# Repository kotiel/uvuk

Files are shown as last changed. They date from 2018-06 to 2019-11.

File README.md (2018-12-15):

# UvuKCube

<br />This work is licensed under a <a rel="license" href="http://creativecommons.org/licenses/by-nc-sa/4.0/">Creative Commons Attribution-NonCommercial-ShareAlike 4.0 International License</a>.

<p align="center" >
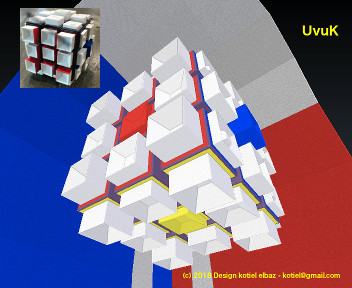
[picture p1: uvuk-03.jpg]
UvuKCube
  
</p>

> Princess UvuKiri, UvuKCube's sister to help you playing with the UvuKCube - fun to build for the children.

> Follow **@uvukcube** on Instagram and Twitter, soon the UvuKiri build guide.

## Qu’est-ce l’UvuK Cube?

La capacité de l’esprit à anticiper un parcours 3D d'une position A vers une position B dans l’espace 3D s'apprend.
**UvuKCube** vous permet d’imaginer ce parcours en 3D (Troisième Dimension), avec vos sensations tactiles du bout des doigts guidées par les cubignons **PiK** et **LaK**.

## What is the UvuKCube?

Imagine you could improve your mind path 3D modeler to move objects around in 3D Space.

**UvuKCube** allows you to imagine a 3D path and execute it, even if you were visually impaired - with your fingers tips, thanks to the cubignons **PiK** and **LaK**.

Discover 3D Printing, Blender3D, even the documentation explains how to re-do a cube.

Trop cool Instagram video of [cubignons](https://instagram.com/p/BknzR3xnqnM/) being 3D printed. 

> Hello cubers.

> UvuKCube is a 3D Kit to bring the Rubik’s cube in the classroom of visually impaired children - Your help is welcome as you build it yourself by 3D printing the ‘CUBIGNONS PiK and LaK’ and then give it to a blind child. Thanks to the UvuKCube, the colours become a sensitive feeling.
A lot to learn 3D software BLENDER3D, 3D Printers, Cubignons PiK and LaK, concave, convex, painting, glue and a lot of fun to teach a blind child to master UvuKCube as well as you master the Rubik’s cube.
UvuKCube’s Cubignons PiK and LaK are Creative Commons, you are free to 3D print them, to modify them to create new UvuKCube.

Thanks to [La Cité des Sciences Fab Lab Paris](http://carrefour-numerique.cite-sciences.fr/fablab/wiki/doku.php?id=projets:uvuk_cube)

``` bash
To follow the Cubignons PiK and LaK, and more
FB fb.me/uvukcube
Instagram @uvukcube #uvukcube
Email uvukcube@gmail.com

Bon Courage, 2018, June 1st
> K.
```

<br />This work is licensed under a <a rel="license" href="http://creativecommons.org/licenses/by-nc-sa/4.0/">Creative Commons Attribution-NonCommercial-ShareAlike 4.0 International License</a>.

Licence Creative Commons Français (BY) (SA) (NC) https://creativecommons.org/licenses/by-nc/4.0/deed.fr

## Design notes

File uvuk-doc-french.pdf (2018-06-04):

# UvuK Cube

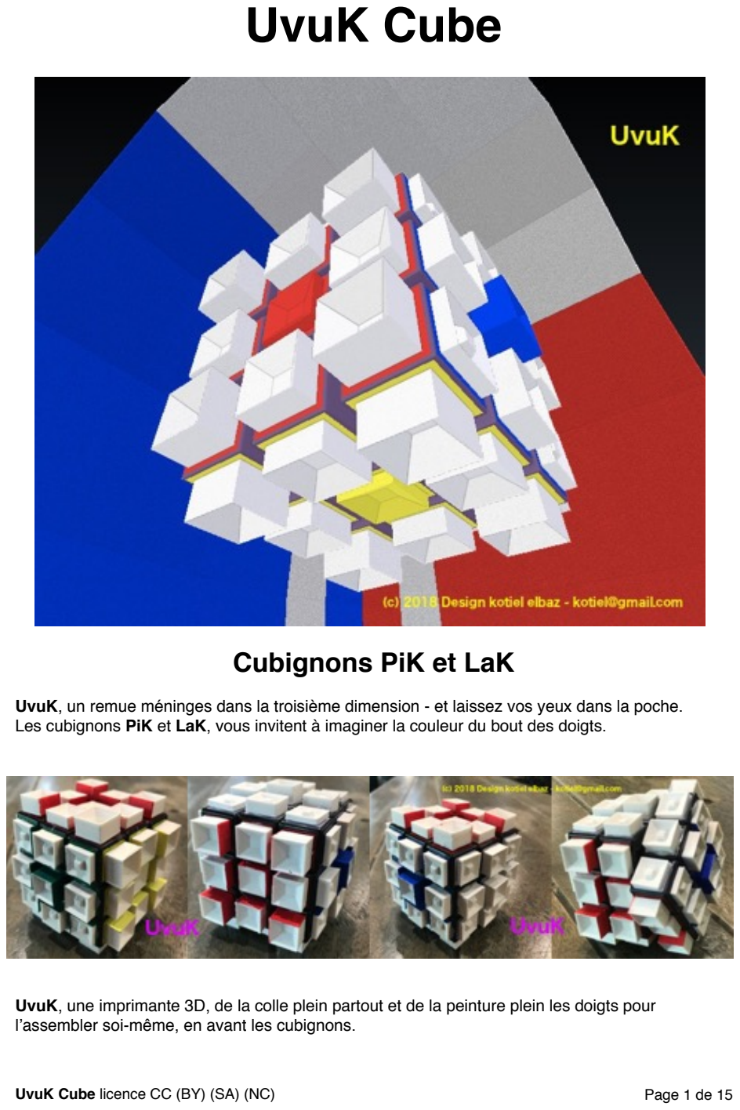
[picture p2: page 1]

## Cubignons PiK et LaK

UvuK, un remue méninges dans la troisième dimension - et laissez vos yeux dans la poche. Les cubignons PiK et LaK, vous invitent à imaginer la couleur du bout des doigts.

UvuK, une imprimante 3D, de la colle plein partout et de la peinture plein les doigts pour l’assembler soi-même, en avant les cubignons.

UvuK Cube licence CC (BY) (SA) (NC) | Page 1 de 15

UvuK Cube | 1
Cubignons PiK et LaK | 1
Assemblage | 3
La liste | 3
Uvuk Cube | 4
Uvuk Face | 5
Refaire Uvuk | 7
UvuK | 7
Les formules | 8
F01 - F02 - Rangée centrale | 9
F03 - Position Croix | 10
F04 - F05 - Orientation Croix | 11
F06 - Position Coins | 12
F07 - Orientation Coins | 13
Liste des fichiers | 14
Embûche | 15
Logiciel | 15
UvuK Licence | 15
UvuK Cube licence CC (BY) (SA) (NC) | Page 2 de 15

## Assemblage

## La liste

### Un Cube

La partie mécanique du Rubik’®s cube est utilisée comme un support.

- Un cube a six faces, chacune est composée de 9 facettes
- Les neuf facettes sont de la même couleur
- La facette centrale donne la couleur de la face
- La facette centrale reste à la même position malgré des rotations

### Le Cubignon

Le cubignon est un cube de la taille d’une facette. Il se colle sur une facette. Il y a deux types de cubignons
- Le cubignon LaK est une cuvette dépouillée
- Le cubignon PiK est une cuvette avec en son fond une bossette

PiK et LaK, les cubignons ont trois hauteurs : 9mm, 6mm et 3mm.

### Face de Cubignons

Une face est un ensemble de neuf cubignons PiK ou de neuf cubignons LaK.
L’ agencement des cubignons par hauteur permet de composer une face convexe ou concave. LA FACE CONVEXE
- Le cubignon central est le petit de 3mm, aux 4 coins se sont les grands de 9mm et les 4 sur les côtés, entre les coins se sont les moyens de 6mm
LA FACE CONCAVE
- Le cubignon central est le grand de 9mm, aux 4 coins sont les petits de 3mm et les 4 sur les côtés, entre les coins se sont les moyens de 6mm

### Collage du Cubignon

Avec un grand total de 54 cubignons crées avec une imprimante 3D, un fer à colle est moyen pratique pour les fixer sur les facettes d’un cube.

### Coloriage du Cubignon

On peut en exemple choisir comme couleur celle de la facette centrale de la face où on colle le cubignon :
- le cubignon central : peindre les quatre côtés
- le cubignon coin : peindre les deux côtés intérieures
- le cubignon côté : peindre le côté en vis à vis du cubignon central
UvuK Cube licence CC (BY) (SA) (NC) | Page 3 de 15

## Uvuk Cube

### Vues par Face

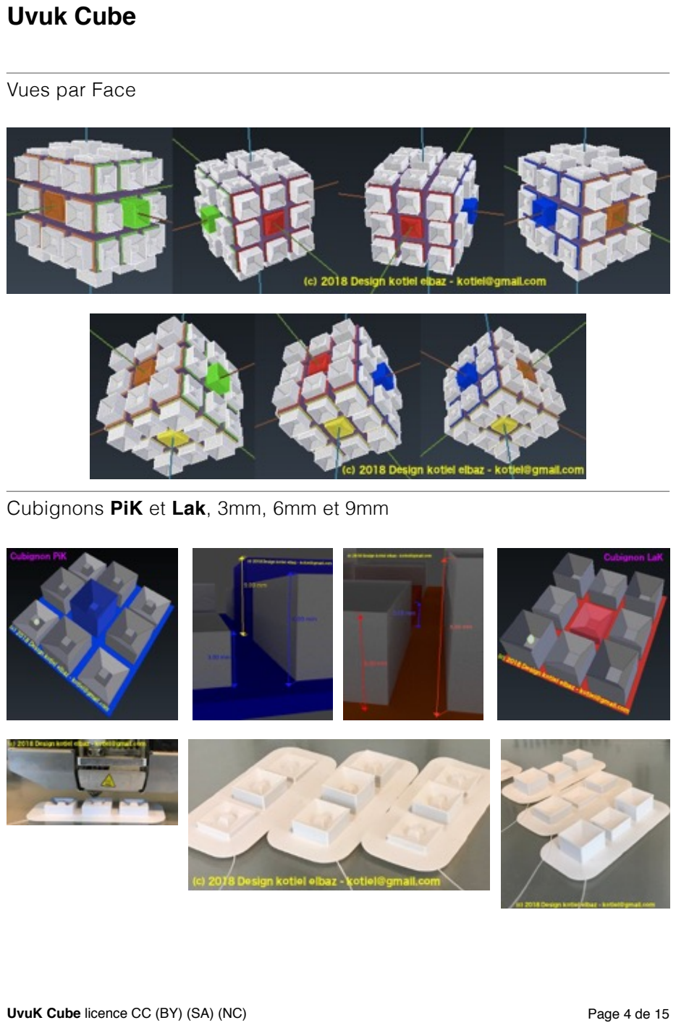
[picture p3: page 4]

### Cubignons PiK et Lak, 3mm, 6mm et 9mm

UvuK Cube licence CC (BY) (SA) (NC) | Page 4 de 15

## Uvuk Face

### Face Concave

Une face concave est composée de 9 cubignons.
Au centre, un cubignon de hauteur 9mm.
A droite, à gauche, au-dessus et en-dessous (en croix) du cubignon central, les cubignons ont une hauteur de 6mm - 4 cubignons.
Aux coins, les cubignons ont une hauteur de 3mm - 4 cubignons coins.

### Face Convexe

Une face convexe est composée de 9 cubignons.
Au centre, un cubignon de hauteur 3mm.
A droite, à gauche, au-dessus et en-dessous (en croix) du cubignon central, les cubignons ont une hauteur de 6mm - 4 cubignons.
Aux coins, les cubignons ont une hauteur de 9mm - 4 cubignons coins.

### La Face convexe et la Face concave

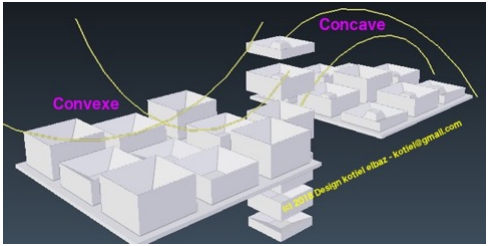
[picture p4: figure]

UvuK Cube licence CC (BY) (SA) (NC) | Page 5 de 15

### Assemblage UvuK

Impression 3D de
- 3 faces concaves de cubignons PiK
- 3 faces convexes de cubignons LaK

Collage des cubignons
- Face rouge, jaune et orange sont des faces convexes de cubignons LaK
- Face bleu, blanche et verte sont des faces concaves de cubignons PiK

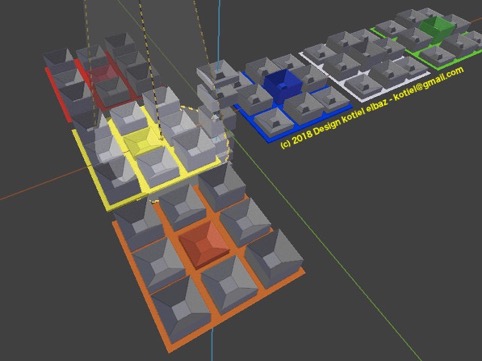
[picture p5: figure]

UvuK Cube licence CC (BY) (SA) (NC) | Page 6 de 15

## Refaire Uvuk

UvuK design permet de manipuler la position des cubignons d’un UvuK de manière tactile. Uvuk est composé de trois faces concaves PiK et de trois faces convexes LaK :
- La face avant (rouge) et la face arrière (orange) sont des faces convexes LaK
- La face gauche (verte) et la droite (bleu) sont des faces concaves PiK
- La face haute (blanche) est concave PiK et la face du dessous (jaune) est convexe LaK

## UvuK

Uvuk possède 6 faces, chacune avec huit facettes mobiles et une non-mobile.
En effet, le cubignon central est mécaniquement en bout d’axe - seule la rotation est possible. Les formules ci-dessous donnent une liste de sens de rotation gauche/droite ou avant/arrière par face afin de décrire les étapes pour déplacer des cubignons.
- Les faces avant, arrière, haute et bas pivotent vers la droite ou vers la gauche
- Les faces gauche et droite pivotent dans le sens en avant ou en arrière
La position de départ est un cubignon central LaK en dessous, un cubignon central LaK en avant et un cubignon central PiK en haut - la face rouge est devant.

### Central, Coin, Côté

Le coin : il est composé de trois facettes, sur une face adjacente différente - UvuK a six coins. Le côté : il est composé de deux facettes, sur une face adjacente différente - une face est composée de quatre cotés. Entre deux coins, il y a un côté - formant une croix autour du cubignon central.
UvuK, on trouve centre de chaque face un cubignon PiK de 3mm/9mm, ou bien un cubignon LaK de 3mm/9mm.
La hauteur 3mm ou 9mm du cubignon central détermine le type convexe ou concave d’une face.

### Identification des faces

Exemple : tourner la face à votre droite d’une rotation vers l’arrière s’écrit : FaceDroite.vers.arrière

| PiK | LaK | Convexe | Concave | Position par défaut | Sens de rotation
Rouge | | LaK | Convexe | | AVANT | Droite/Gauche
Orange | | LaK | Convexe | | ARRIÈRE | Droite/Gauche
Bleu | PiK | | | Concave | DROITE | Avant/Arrière
Vert | PiK | | | Concave | GAUCHE | Avant/Arrière
Blanc | PiK | | | Concave | HAUTE | Droite/Gauche
Jaune | | LaK | Convexe | | BAS | Droite/Gauche
UvuK Cube licence CC (BY) (SA) (NC) | Page 7 de 15

## Les formules

### Etape I - Face Haute

UvuK, une fois tous les cubignons mélangés, les formules suivantes permettent de déplacer les cubignons par étapes afin de les remettre tous en postions.
On commence par faire la face du haut. Il faut apprendre par soi-même cette étape, c’est un bon exercice pour la mémoire visuelle et tactile, aussi la maîtrise du déplacement des cubignons.

UvuK position de référence :
- un cubignon central LaK devant (rouge), un cubignon central LaK en bas (jaune) et un cubignon central PiK en haut (blanc)

Pour rassembler la première face :
- Positionner les quatre coins - quatre cubignons PiK de la face concave haute (blanche)
- Positionner les côtés - une situation embêtante est avec un cubignon du dessus est sur la face du dessous (jaune) - courage vous trouverez la solution
- Positionner les cubignons de la face afin que la couronne soit d’une couleur identique pour chaque face latérale - utiliser la couleur du cubignon central d’une face adjacente

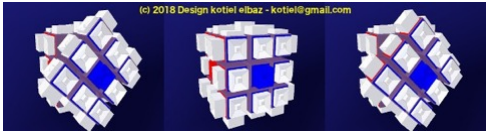
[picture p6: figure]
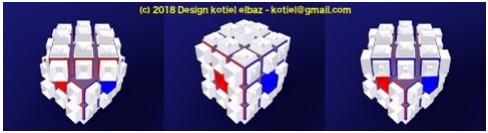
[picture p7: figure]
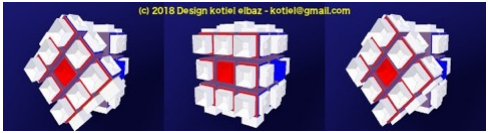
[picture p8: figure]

UvuK Cube licence CC (BY) (SA) (NC) | Page 8 de 15

### Etape II - Rangée centrale

La rangée centrale est composée de 4 cubignons centrals et de 4 cubignons côtés - on applique F01 ou F02 en complétant une face à la fois.
Seuls des cubignons côtés sont à positionner - 4 pour faire la rangée.

Quand un cubignon est en place et mal orienté, on applique en premier la formule F01 ou F02 avec un quelconque cubignon de la face du bas pour le déplacer, ensuite une nouvelle fois F01 ou F02 pour le positionner correctement.

F01 fait monter le cubignon de la face du bas vers la droite, la formule F02 vers la gauche.

## F01 - F02 - Rangée centrale

### F01 - Cubignon Bas va à Droite vers rangée centrale

### F02 - Cubignon Bas va à Gauche vers rangée centrale

Etape 1 | Etape 2 | Etape 3 | Etape 4
FaceBas.vers.gauche | FaceDroite.vers.avant | FaceBas.vers.droite | FaceDroite.vers.arrière
Etape 5 | Etape 6 | Etape 7 | Etape 8
FaceBas.vers.droite | FaceAvant.vers.droite | FaceBas.vers.gauche | FaceAvant.vers.gauche
Etape 1 | Etape 2 | Etape 3 | Etape 4
FaceBas.vers.droite | FaceGauche.vers.avant | FaceBas.vers.gauche | FaceGauche.vers.arrière
Etape 5 | Etape 6 | Etape 7 | Etape 8
FaceBas.vers.gauche | FaceAvant.vers.gauche | FaceBas.vers.droite | FaceAvant.vers.droite

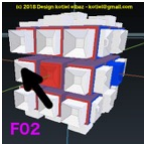
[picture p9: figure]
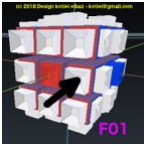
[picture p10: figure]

UvuK Cube licence CC (BY) (SA) (NC) | Page 9 de 15

### Etape III - Rangée du bas

On oriente Uvuk, avec la face convexe LaK (jaune) comme la face du dessus.

## F03 - Position Croix

L’objectif est une croix de quatre cubignons côtés autour du cubignon central (LaK de 3mm -jaune). On positionne la croix, sans se soucier de ses facettes adjacentes, c’est à dire les cubignons en croix sont tous des LaK de 6mm (jaune) au dessus, la position de l’anneau latéral se fait avec la prochaine formule.
F03 positionne seulement deux côtés à la fois. Quand on a deux cubignons adjacents, tournez la face pour orienter les deux cubignons en haut et à gauche.

La formule F03 est à utiliser plusieurs fois de suite, afin d’orienter les quatre cubignons.

### F03 - Position de croix

Etape 1 | Etape 2 | Etape 3 | Etape 4
FaceDroite.vers.avant | FaceHaute.vers.gauche | FaceAvant.vers.gauche | FaceHaute.vers.droite
Etape 5 | Etape 6
FaceAvant.vers.droite | FaceDroite.vers.arrière

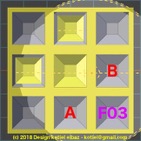
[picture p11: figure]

UvuK Cube licence CC (BY) (SA) (NC) | Page 10 de 15

## F04 - F05 - Orientation Croix

La croix du dessus - 4 cubignons LaK 6mm (jaune) - est en position. Les formules F04 et F05 permettent une rotation circulaire des cubignons côtés sans une modification d’orientation.
Les formules F04 et F05 déplacent le cubignon de la position A vers la droite (F04) ou bien vers le bas (F05). Dans certains cas, il est nécessaire d’appliquer F04 plusieurs fois de suite, pour obtenir la position de départ avec un bon côté à gauche - au besoin tourner la face du dessus pour sélectionner le cubignon à positionner à gauche avant d’appliquer F04.

Les formules F04 et F05 sont à connaître par coeur ;).

### F04 - Rotation circulaire, le cubignon haut va à droite

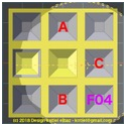
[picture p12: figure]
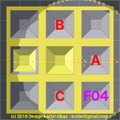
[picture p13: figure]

### F05 - Rotation circulaire, le cubignon haut va en bas

Etape 1 | Etape 2 | Etape 3 | Etape 4 | Etape 5
FaceDroite.vers.arrière | FaceHaute.vers.droite | FaceDroite.vers.avant | FaceHaute.vers.droite | FaceDroite.vers.arrière
Etape 6 | Etape 7 | Etape 8 | Etape 9 | Etape 10
FaceHaute.vers.droite | FaceHaute.vers.droite | FaceDroite.vers.avant | FaceHaute.vers.droite | FaceHaute.vers.droite
Etape 1 | Etape 2 | Etape 3 | Etape 4 | Etape 5
FaceDroite.vers.avant | FaceHaute.vers.gauche | FaceDroite.vers.arrière | FaceHaute.vers.gauche | FaceDroite.vers.avant
Etape 6 | Etape 7 | Etape 8 | Etape 9 | Etape 10
FaceHaute.vers.droite | FaceHaute.vers.droite | FaceDroite.vers.arrière | FaceHaute.vers.droite | FaceHaute.vers.droite

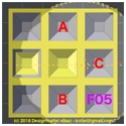
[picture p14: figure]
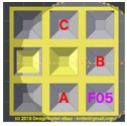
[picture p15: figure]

UvuK Cube licence CC (BY) (SA) (NC) | Page 11 de 15

## F06 - Position Coins

La croix de cubignons 6mm est en place autour du cubignon LaK central (jaune), tous les côtés ont leur faces adjacentes en position.

Cette étape s’occupe uniquement de positionner les 4 coins.

Avec un coin en bonne position - l’orientation de ses facettes est sans importance. On oriente l’Uvuk - sans tourner la face, de façon à positionner ce coin en haut et à gauche.

La rotation des trois autre coins, se fait avec la formule F06 - elle s’utilise autant de fois pour les positionner correctement.

Lorsque les quatre coins ont une position incorrecte. Utiliser la formule F06 plusieurs fois de suite pour obtenir un des cubignons coin en bonne position. On oriente alors l’UvuK pour positionner celui-ci en haut et à gauche.

F06 fait tourner la position les trois coins, A, B, et C tandis que le coin du haut à gauche reste en position - l’orientation des facettes des coins se fait avec la prochaine formule.

### F06 - Rotation circulaire droite des coins

Etape 1 | Etape 2 | Etape 3 | Etape 4 | Etape 5
FaceDroite.vers.avant | FaceGauche.vers.avant | FaceHaute.vers.droite | FaceGauche.vers.arrière | FaceHaute.vers.gauche
Etape 6 | Etape 7 | Etape 8 | Etape 9 | Etape 10
FaceDroite.vers.arrière | FaceHaute.vers.droite | FaceGauche.vers.avant | FaceHaute.vers.gauche | FaceGauche.vers.arrière

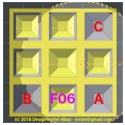
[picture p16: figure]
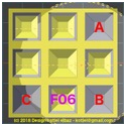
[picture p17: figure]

UvuK Cube licence CC (BY) (SA) (NC) | Page 12 de 15

## F07 - Orientation Coins

F07 - Courage, on utilise les précédentes formules F04 et F05 pour la dernière étape.

Les coins sont en position et seule l’orientation de leurs facettes est à positionner.

L’orientation des facettes de deux coins de faces opposées est obtenue avec les formules F04 et F05 faite l’une à la suite de l’autre.

Positionner à votre gauche les facettes A/B/C et D/E/F, comme sur l’image gauche ci-dessous. Faire en premier F04, puis sans bouger l’UvuK d’orientation faire F05.
La facette A de la face avant et la facette F de la face arrière montent sur la face du dessus. Les deux autres facettes des coins vont tourner aussi et se positionner correctement.

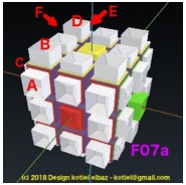
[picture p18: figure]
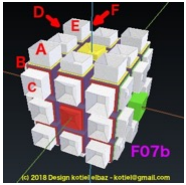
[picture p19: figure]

UvuK Cube licence CC (BY) (SA) (NC) | Page 13 de 15

## Liste des fichiers

### Blender 3D

UvuK et les cubignons PiK et LaK sont modélisés avec le logiciel Blender 3D.

### CURA

Les fichiers gcode des cubignons sont généré avec le logiciel d’Imprimante 3D CURA.

Nom du fichier | Contenu | Elaboré avec | Usage
uvuk-kte.blend | modèle 3D des cubignons | Blender3D | prototype et design d’UvuK
uvuk-lak-3mm.stl | fichier STL | Blender3D | UvuK cubignon LaK de 3mm
uvuk-lak-6mm.stl | fichier STL | Blender3D | UvuK cubignon LaK de 6mm
uvuk-lak-9mm.stl | fichier STL | Blender3D | UvuK cubignon LaK de 9mm
uvuk-pik-3mm.stl | fichier STL | Blender3D | UvuK cubignon PiK de 3mm
uvuk-pik-6mm.stl | fichier STL | Blender3D | UvuK cubignon PiK de 6mm
uvuk-pik-9mm.stl | fichier STL | Blender3D | UvuK cubignon PiK de 9mm
uvuk-ccv-face.stl | fichier STL | Blender3D | UvuK face concave PiK
uvuk-cvx-face.stl | fichier STL | Blender3D | UvuK face convexe LaK
Nom de fichier | Description | Elaboré avec | Contenu
UM2+_uvuk-lak-r01.gcode | fichier gcode pour imprimante 3D | CURA | rangée de 3 cubignons LaK - 1 central de 6mm et 2 de 9mm
UM2+_uvuk-lak-rc01.gcode | fichier gcode pour imprimante 3D | CURA | rangée centrale de 3 cubignons LaK - 1 central de 3mm et 2 de 6mm
UM2+_uvuk-pik-r01.gcode | fichier gcode pour imprimante 3D | CURA | rangée de 3 cubignons PiK - 1 central de 6mm et 2 de 3mm
UM2+_uvuk-pik-rc01.gcode | fichier gcode pour imprimante 3D | CURA | rangée centrale de 3 cubignons PiK - 1 central de 9mm et 2 de 6mm
Face UvuK | Nom de fichier | Impression 3D par face | Impression 3D pour UvuK complet
Face convexe | UM2+_uvuk-lak-r01.gcode | 2 exemplaires | 6 exemplaires
Face convexe | UM2+_uvuk-lak-rc01.gcode | 1 exemplaire | 3 exemplaires
Face concave | UM2+_uvuk-pik-r01.gcode | 2 exemplaires | 6 exemplaires
Face concave | UM2+_uvuk-pik-rc01.gcode | 1 exemplaire | 3 exemplaires
UvuK Cube licence CC (BY) (SA) (NC) | Page 14 de 15

## Embûche

- Les cubignons sont imprimés 3 par 3 avec un socle - Pour les séparer, une paire de ciseaux suffit.
- La couleur des cubignons par défaut est le blanc. Cependant, au cas ou plusieurs se détachent, il est difficile de retrouver leurs places respectives. Mon choix a été de peindre les faces interne des cubignons.
- Une bonne dose de colle est nécessaire, l’utilisation d’un fer à colle permet d’obtenir un collage assez solide - la colle de type super-glue reste la solution de référence. Avec 54 cubignons à positionner … éviter les erreurs.
- Pour re-faire l’UvuK, on peut avoir besoin d’appliquer une formule en premier pour déplacer un cubignon central, coin ou côté en mauvaise position, puis de nouveau la même formule ou autre pour le positionner correctement.
- Au repos, UvuK aime bien avoir ses pieds LaK (jaune) reposant sur le sol et souriant avec LaK (rouge) devant.

## Logiciel

Logiciel Blender 3D : blender.org
Imprimante 3D Ultimaker 2+ et logiciel CURA : ultimaker.org

## UvuK Licence

licence CC (BY) (SA) (NC) Creative Commons, Attribution, Share-alike, Non-commercial.

1er Juin - 2018

Bon Courage,
Kotiel Elbaz

Instagram @uvukcube #uvukcube Email uvukcube@gmail.com

UvuK Cube licence CC (BY) (SA) (NC) | Page 15 de 15

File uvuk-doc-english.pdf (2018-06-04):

# UvuK Cube

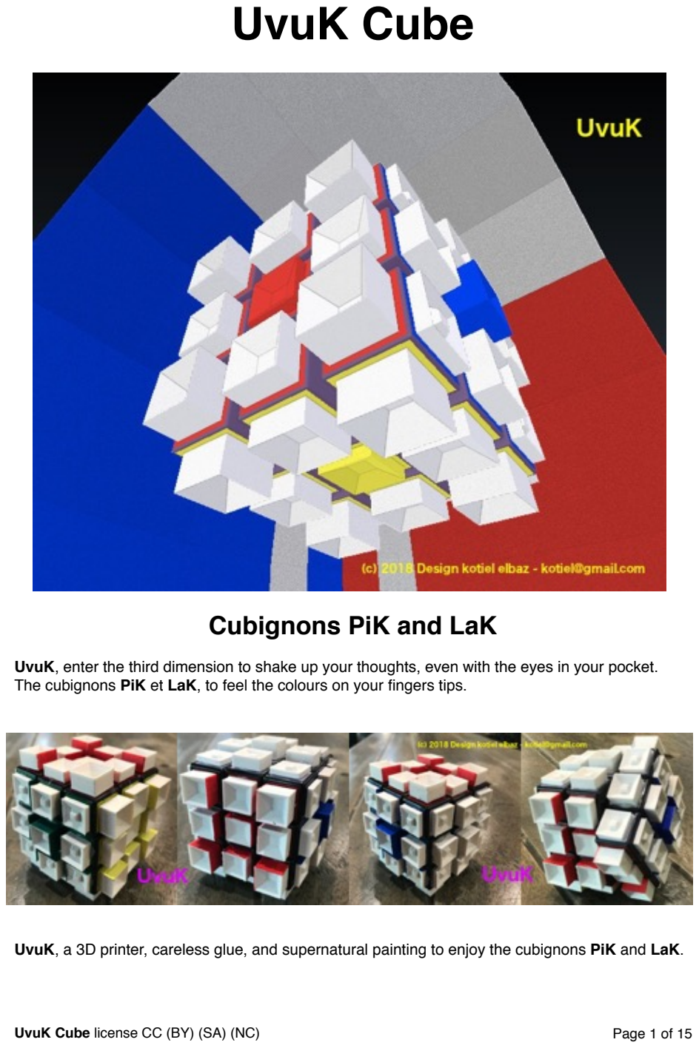
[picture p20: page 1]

## Cubignons PiK and LaK

UvuK, enter the third dimension to shake up your thoughts, even with the eyes in your pocket. The cubignons PiK et LaK, to feel the colours on your fingers tips.

UvuK, a 3D printer, careless glue, and supernatural painting to enjoy the cubignons PiK and LaK.

UvuK Cube license CC (BY) (SA) (NC) | Page 1 of 15

UvuK Cube | 1
Cubignons PiK and LaK | 1
Assemblage | 3
The list | 3
Uvuk Cube | 4
Uvuk Surface | 5
Re-do Uvuk | 7
UvuK | 7
The formules | 8
F01 - F02 - Center row | 9
F03 - Position Cross | 10
F04 - F05 - Orientation Cross | 11
F06 - Position Corner | 12
F07 - Orientation Corners | 13
Files list | 14
Ambush | 15
Software | 15
UvuK License | 15
UvuK Cube license CC (BY) (SA) (NC) | Page 2 of 15

## Assemblage

## The list

### The Cube

The cubignons stand on top of a Rubik’®s cube frame.

- A cube has six sides, each of them with 9 squares
- The nine squares have the same colour
- The central square colour of each side is the reference used for all the colour side
- The cubignon on the central square remain at this position whatever the rotation

### The Cubignon

Le cubignon is a tiny cube to glue on a square of the cube side. There are two kinds of cubignons
- The cubignon LaK is an hollow cavity
- The cubignon PiK is an hollow cavity with a knob at its bottom

PiK et LaK, both of them are 3D printed in three heights of 3mm, 6mm and 9mm..

### Surface of cubignons

Each cube sides own a total of 9 cubignons PiK or of 9 cubignons LaK.
The outline position of various cubignons heights allows to shape of two surfaces type.

THE CONVEX SURFACE
- A central small cubignon of height 3mm, the side - between the 4 corners - a medium cubignon of height 6mm and at each corners there is a tall cubignon of height 9mm THE CONCAVE SURFACE
- A central tall cubignon of height 9mm, the side - between the 4 corners - medium cubignon of height 6mm and at each corners there is a tall cubignon of height 3mm

### Glue for Cubignon

There is a grand total of 54 3D printed cubignons, the heated glue iron is a practical way to glue the cubignons on the cube.

### Paint my Cubignon

Some cubignon’s side are selected for painting with the colour of the cube center side square :
- The cubignon central : paint all its sides
- The cubignon corner : the both sides located inside toward the central cubignon
- The cubignon side : only the side in front of the central cubignon
UvuK Cube license CC (BY) (SA) (NC) | Page 3 of 15

## Uvuk Cube

### Sides vues

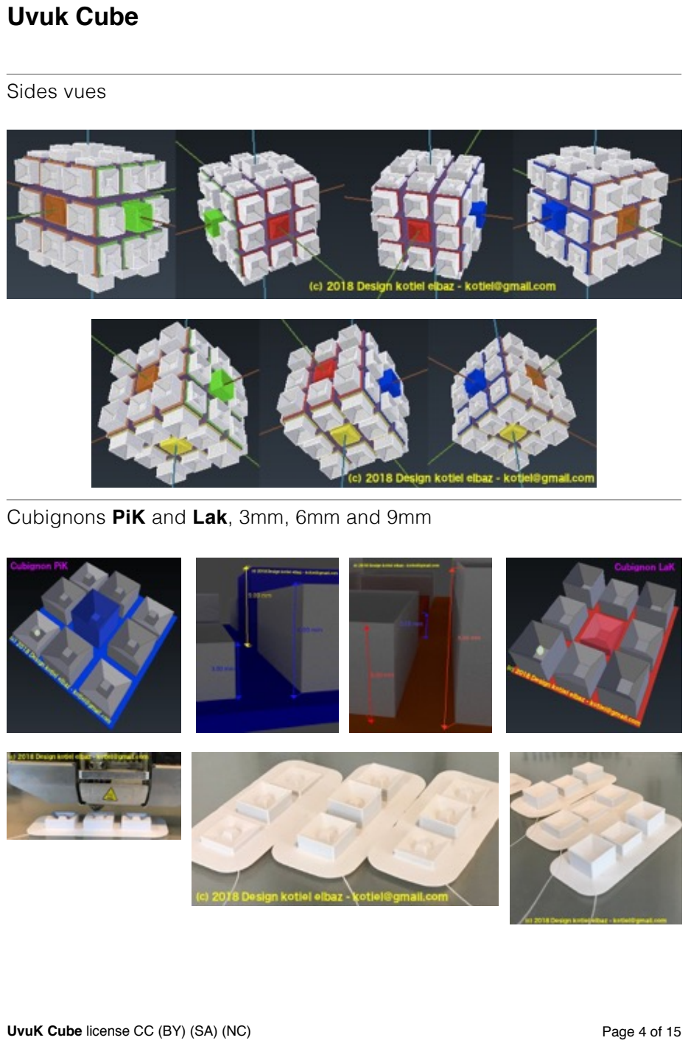
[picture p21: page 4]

### Cubignons PiK and Lak, 3mm, 6mm and 9mm

UvuK Cube license CC (BY) (SA) (NC) | Page 4 of 15

## Uvuk Surface

### Concave Side

The center one is a 9mm height.
On the right, left, above and below (cross) from the central cubignon, it’s a 6mm height cubignon -4 of them.
On all the 4 corners, the cubignons height is a 3mm.

### Convex Side

The center one is a 3mm height.
On the right, left, above and below (cross) from the central cubignon, it’s a 6mm height cubignon -4 of them.
On all the 4 corners, the cubignons height is a 9mm.

### Convex and Concave Surface


UvuK Cube license CC (BY) (SA) (NC) | Page 5 of 15

### Assemblage UvuK

3D prints to build
- 3 concave surfaces of PiK cubignons
- 3 convex surfaces of LaK cubignons

Glue the cubignons to
- Red, yellow, orange cube sides to form a convex surface of LaK cubignons
- Blue, white and green cube sides to form a concave surface of PiK cubignons


UvuK Cube license CC (BY) (SA) (NC) | Page 6 of 15

## Re-do Uvuk

The aim behind UvuK, first to be able to move back all the cubignons to their reference position. The cubignons outline over concave and convex surfaces is designed also to be able to put them back using only your fingers tips.
UvuK got 3 concave sides of PiK and 3 convex sides of LaK :
- The front side (red) and the back side (orange) are convex of LaK
- The left (green) and the right (blue) are concave of PiK
- The top (white) is concave of PiK and the bottom (yellow) is convex of LaK

## UvuK

Uvuk has 6 sides, each sides are sliced in 9 squares.
Each sides central square is attached to the end of an horizontal axe.
The formula below describes the list of rotation with direction left/right or forward/backward, they allow you step by step to move the cubignons around.
Holding UvuK in front of you :
- the front and back sides rotate right and left
- the left and right sides rotate forward or backward
- the top and bottom sides rotate right and left
The start position is a center LaK cubignon at the bottom, a center LaK cubignon in front and a center PiK cubignon on top - same as the red side in front of you.

### Central, Corner, Side

The corner : with three squares, each of them belonging to an adjacent UvuK sides - 6 of them. The side square : the side square has two cubignons, each of them belonging to an adjacent UvuK side - 4 of them per cube side.
A side square is between two corners - a cross of 4 cubignons side square is around a central cubignon.
UvuK, on each of the cube sides, there is a center cubignon PiK or LaK, of a height 3mm or 9mm.

### List of Surfaces

Exemple : pivot the right side by one step backward : sideRight.backward

| PiK | LaK | Convex | Concave | Start Position | Rotation direction
Red | | LaK | Convex | | FRONT | Right/Left
Orange | | LaK | Convex | | BACK | Right/Left
Blue | PiK | | | Concave | RIGHT | Forward/Backward
Green | PiK | | | Concave | LEFT | Forward/Backward
White | PiK | | | Concave | TOP | Right/Left
Yellow | | LaK | Convex | | BOTTOM | Right/Left
UvuK Cube license CC (BY) (SA) (NC) | Page 7 of 15

## The formules

### Step I - Top Side

Randomly scramble all the cubignons over UvuK.
The following formula help you to put them back to their original position.
For this first step, we arrange the cubignons on a top side.
Actually for the first step, do it on your own - it’s a good exercise to train the visual and tactile memory.

The starting position is with UvuK in front of you, a center cubignon LaK in front (red), a center cubignon LaK at the bottom (yellow) and a center cubignon PiK on top (white).

For the first top side :
- Set the four corners in position - 4 PiK 3mm cubignons as it’s a concave top side
- Set the 4 sides square between the four corners - one annoying situation, it’s a top cubignon at a position on the bottom side (yellow) - courage, find the solution by yourself
- As the corners and the sides square are in positions, next is the colour side band around the top side - Use the central cubignon of an adjacent side to know which colour to choose

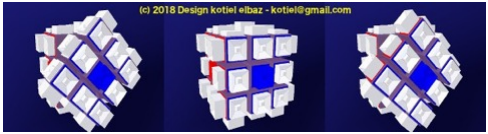
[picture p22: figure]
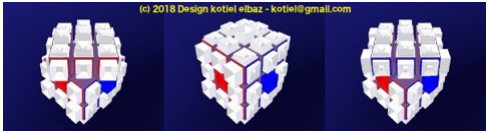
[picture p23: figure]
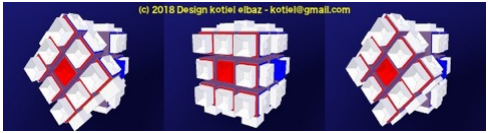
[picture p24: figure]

UvuK Cube license CC (BY) (SA) (NC) | Page 8 of 15

### Step II - Center Row

The Uvuk central row has 4 central cubignons and 4 side square cubignons - This formula is used to complete one UvuK surface at a time - where the center row belongs.

Sometime, a cubignon in position has a wrong orientation. Then, apply F01 or F02 on any bottom cubignons and then use it again (F01 or F02) to move up the correct one in position.
F01 allow you to move one cubignon from the bottom row toward the right, and F02 toward the left middle row.

## F01 - F02 - Center row

### F01 - Cubignon Bottom Row toward Right Central Row

### F02 - Cubignon Bottom Row toward Left central Row

Step 1 | Step 2 | Step 3 | Step 4
sideBottom.left | sideRight.forward | sideBottom.right | sideRight.backward
Step 5 | Step 6 | Step 7 | Step 8
sideBottom.right | sideFront.right | sideBottom.left | sideFront.left
Step 1 | Step 2 | Step 3 | Step 4
sideBottom.right | sideLeft.forward | sideBottom.left | sideLeft.backward
Step 5 | Step 6 | Step 7 | Step 8
sideBottom.left | sideFront.left | sideBottom.right | sideFront.right


UvuK Cube license CC (BY) (SA) (NC) | Page 9 of 15

### Etape III - Difficult Part

Please position Uvuk sunny side up, the LaK convex surface (yellow) on top

## F03 - Position Cross

A cross like of side square cubignons to position around the central one.
The focus is on the orientation at the top, the side row colour order is done at the next step.

F03 formula is orientating only half of the cross at a time - to achieve it, F03 is done multiple times.

As soon as you get two cubignons orientated on the top, position them at the top left - as on the picture below, then apply F03 again.

### F03 - Position cross

Step 1 | Step 2 | Step 3 | Step 4
sideRight.forward | sideTop.left | sideFront.left | sideTop.right
Step 5 Step 6
sideFront.right | sideRight.backward


UvuK Cube license CC (BY) (SA) (NC) | Page 10 of 15

## F04 - F05 - Orientation Cross

The top four cubignons around the center are now in position. The formula F04 and F05 aligns their sides row to match their adjacent sides.
The formula F04 and F05 rotates only 3 cubignons at a time - the picture below.

The left cubignon remains in its position after using F04 or F05. Turn only the top UvuK side to select a start position - multiple start positions are usually possible, experience helps to select the best right start position. Sometimes, you need to apply F04 or F05 only to get a start position then apply F04 or F05 again.
At the end of this step, a full cross is in position with the sides aligned to their adjacente one. Learn the formula F04 and F05 by heart ;).

### F04 - Circular rotation, top cubignon to the right


### F05 - Circular rotation, the top cubignon to bellow

Step 1 | Step 2 | Step 3 | Step 4 | Step 5
sideRight.backward | sideTop.right | sideRight.forward | sideTop.right | sideRight.backward
Step 6 | Step 7 | Step 8 | Step 9 | Step 10
sideTop.right | sideTop.right | sideRight.forward | sideTop.right | sideTop.right
Step 1 | Step 2 | Step 3 | Step 4 | Step 5
sideRight.forward | sideTop.left | sideRight.backward | sideTop.left | sideRight.forward
Step 6 | Step 7 | Step 8 | Step 9 | Step 10
sideTop.right | sideTop.right | sideRight.backward | sideTop.right | sideTop.right

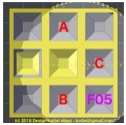
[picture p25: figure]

UvuK Cube license CC (BY) (SA) (NC) | Page 11 of 15

## F06 - Position Corner

This step moves the corners at their correct position - without turning the top side, first locate if one of the four corners is in the right position. If one is in position, then by orienting Uvuk, position the corner at the top left - picture below.
The orientation of the three sides square of the cubignon corner is done with the last next formula.

Use the F06 formula to rotate the three remaining corners, as many times as required until all the corners are in their position.

When at the beginning, there is not a single corners in the correct position, then apply F06 until it happens. Once you get one corner in position - the orientation is done at the next step - then oriente UvuK to have it at the top left position. Apply F06 again until all the corners are at their correct position.
F06 rotates only the corners A, B and C while the corner on the top left remain in position.

### F06 - Circular rotation, corners to the right

Step 1 | Step 2 | Step 3 | Step 4 | Step 5
sideRight.forward | sideLeft.forward | sideTop.right | sideLeft.backward | sideTop.left
Step 6 | Step 7 | Step 8 | Step 9 | Step 10
sideRight.backward | sideTop.right | sideLeft.forward | sideTop.left | sideLeft.backward


UvuK Cube license CC (BY) (SA) (NC) | Page 12 of 15

## F07 - Orientation Corners

Great the last step, the previous formula F04 followed by F05 are re-used.

At this step, the top UvuK side has all its sides square cubignons in position, the corners are in position and it only remain the corners’ orientation to complete UvuK original cubignons positions. Using the formula F04 followed by the F05, it rotates the position A, B and C of the front side, while at the same time on the backside, the position D, E and F also rotate.
Set on your left, the sides square at corner A/B/C and D/E/F positions before using F04, this by orientating UvuK, without turning a cube side.
Once, in position as on F07a picture, apply the previous formula F04 and right away without moving UvuK at the end of F04, then apply the steps of the formula F05.
The others corners sides are also moving to their definitive position.


UvuK Cube license CC (BY) (SA) (NC) | Page 13 of 15

## Files list

### Blender 3D

UvuK and the cubignons PiK et LaK models are designed with Blender 3D software.

### CURA

The gcode file for the cubignons are generated with the 3D printer software CURA.

File name | Content | Created with | Note
uvuk-kte.blend | original 3D cubignons | Blender3D | prototype and design d’UvuK
uvuk-lak-3mm.stl | STL file | Blender3D | UvuK cubignon LaK 3mm
uvuk-lak-6mm.stl | STL file | Blender3D | UvuK cubignon LaK 6mm
uvuk-lak-9mm.stl | STL file | Blender3D | UvuK cubignon LaK 9mm
uvuk-pik-3mm.stl | STL file | Blender3D | UvuK cubignon PiK 3mm
uvuk-pik-6mm.stl | STL file | Blender3D | UvuK cubignon PiK 6mm
uvuk-pik-9mm.stl | STL file | Blender3D | UvuK cubignon PiK 9mm
uvuk-ccv-face.stl | STL file | Blender3D | UvuK concave PiK
uvuk-cvx-face.stl | STL file | Blender3D | UvuK convex LaK
File name | Content | Created with | Note
UM2+_uvuk-lak-r01.gcode | gcode file used by 3D Printer | CURA | row of 3 cubignons LaK - 1 central of 6mm and 2 of 9mm
UM2+_uvuk-lak-rc01.gcode | gcode file used by 3D Printer | CURA | row central of 3 cubignons LaK - 1 central of 3mm and 2 of 6mm
UM2+_uvuk-pik-r01.gcode | gcode file used by 3D Printer | CURA | row of 3 cubignons PiK - 1 central of 6mm and 2 of 3mm
UM2+_uvuk-pik-rc01.gcode | gcode file used by 3D Printer | CURA | row central of 3 cubignons PiK - 1 central of 9mm and 2 of 6mm
UvuK surface | File name | 3D Print one side | 3D Print full UvuK
Convex | UM2+_uvuk-lak-r01.gcode | 2 instances | 6 instances
Convex | UM2+_uvuk-lak-rc01.gcode | 1 instance | 3 instances
Concave | UM2+_uvuk-pik-r01.gcode | 2 instances | 6 instances
Concave | UM2+_uvuk-pik-rc01.gcode | 1 instance | 3 instances
UvuK Cube license CC (BY) (SA) (NC) | Page 14 of 15

## Ambush

- The cubignons are 3D printed on 3 by 3 stand, a scissor is good enough to separate them.
- The default colour for the cubignon is white. However, if more than one drop, it’s difficult to find out where to put them back. My choice is to paint only some cubignon’s sides.
- To glue the cubignons on the cube, an iron glue is convenient. A fair amount of glue on the cubignon side achieves a good result - a super-glue like is recommended for an intensive UvuK usage. More glue means more difficult to remove … also with 54 cubignons to go, watch your mistakes.
- While re-doing UvuK, when the cubignons position looks like to be blocking a first formula then use the formula to move it out from a wrong position, and then apply the same or another formula to put back the right cubignon in position.
- At rest, UvuK loves to smile red side in front, and its yellow foot on the ground ;).

## Software

Software Blender 3D : blender.org
3D Printer Ultimaker 2+ with software CURA : ultimaker.org

## UvuK License

license CC (BY) (SA) (NC) Creative Commons, Attribution, Share-alike, Non-commercial

June, 1st - 2018

Bon Courage,
Kotiel Elbaz

Instagram @uvukcube #uvukcube Email uvukcube@gmail.com

UvuK Cube license CC (BY) (SA) (NC) | Page 15 of 15

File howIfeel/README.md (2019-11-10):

# HOWIFEEL DIRECTORY

> The files in this directory uvuk/howifeel

> This work is licensed under a Creative Commons Attribution 4.0 International License.

<br />This work is licensed under a <a rel="license" href="http://creativecommons.org/licenses/by/4.0/">Creative Commons Attribution 4.0 International License</a>.



File : instagramtwitter-uvukcube-logomerge-v01.png

File : qsys-greta-d0810-4kp02.mov

> **@uvukcube** on Twitter

<br />This work is licensed under a <a rel="license" href="http://creativecommons.org/licenses/by/4.0/">Creative Commons Attribution 4.0 International License</a>.

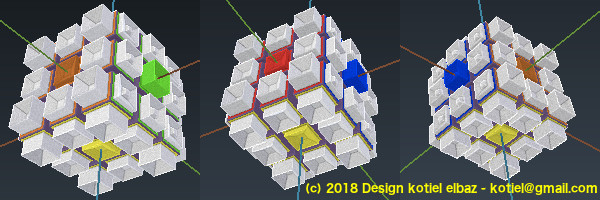
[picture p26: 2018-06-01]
uvuk-pic/uvuk-ap04-02.jpg

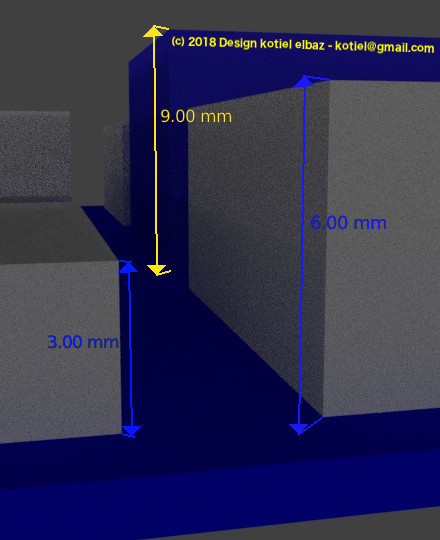
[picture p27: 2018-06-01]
uvuk-pic/uvuk-ap04-06.jpg

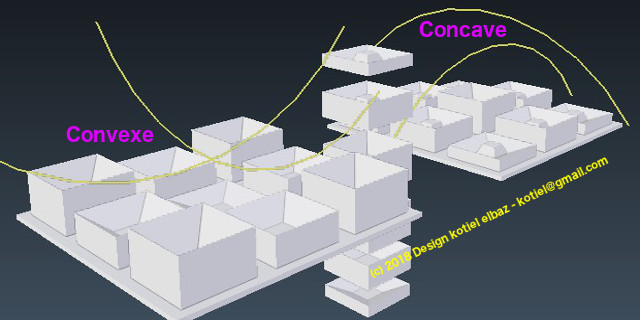
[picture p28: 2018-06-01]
uvuk-pic/uvuk-ap05-01.jpg

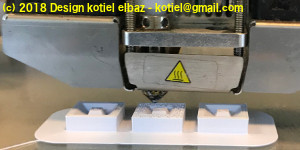
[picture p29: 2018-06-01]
uvuk-pic/uvuk-ap01-14.jpg

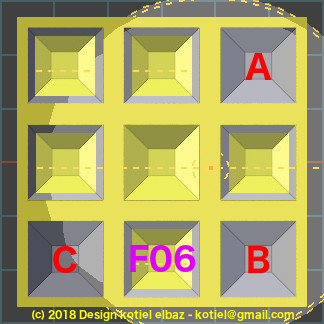
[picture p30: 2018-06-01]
uvuk-pic/uvuk-ap12-f06-cr1.jpg

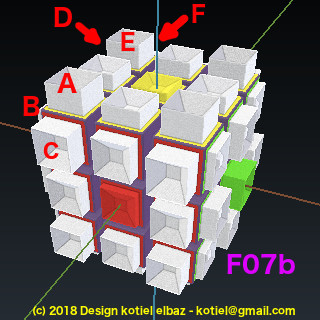
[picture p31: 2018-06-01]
uvuk-pic/uvuk-ap12-f07a-badc.jpg

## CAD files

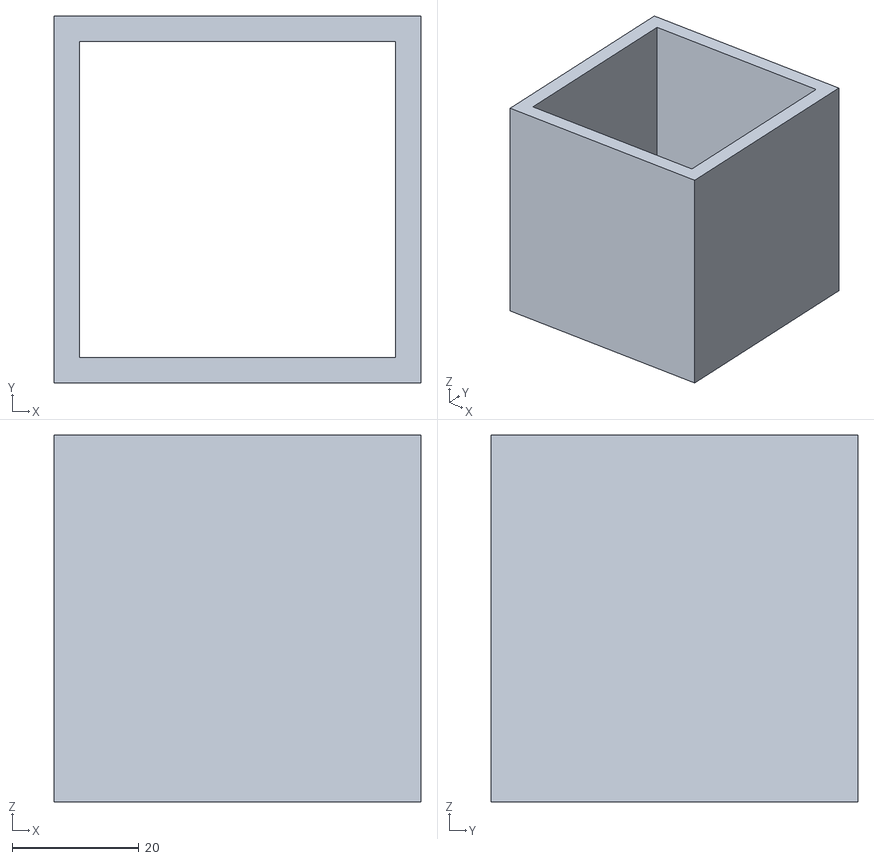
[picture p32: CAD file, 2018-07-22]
uvuk-stl/uvukiri-cube.stl
58.0 x 58.0 x 58.0

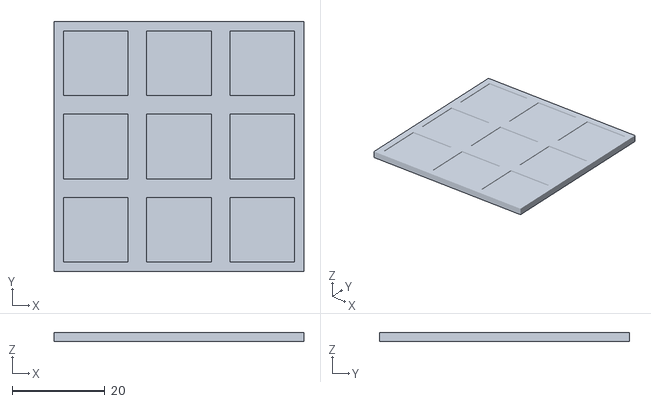
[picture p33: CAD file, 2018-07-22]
uvuk-stl/uvukiri-plate2mm.stl
54.0 x 54.0 x 2.00

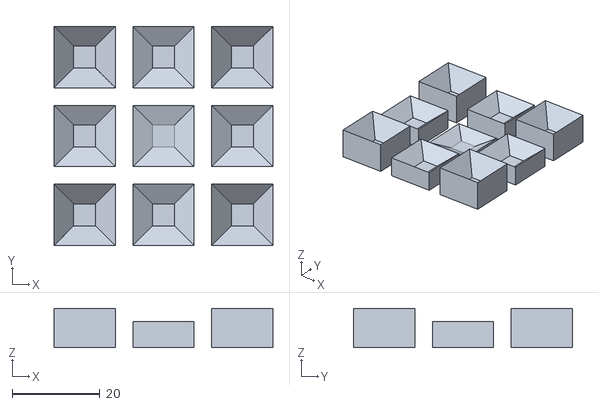
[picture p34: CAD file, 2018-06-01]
uvuk-stl/uvuk-cvx-face.stl
50.0 x 50.0 x 9.00

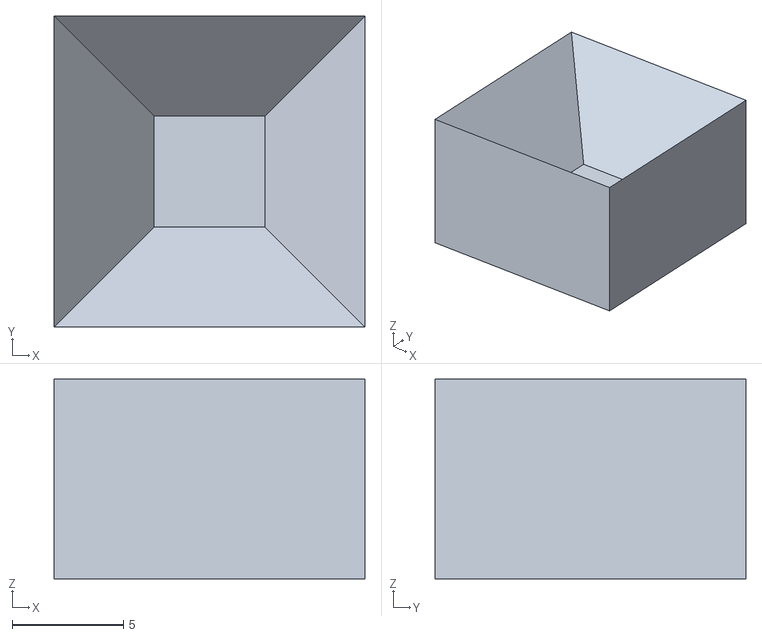
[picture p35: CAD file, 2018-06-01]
uvuk-stl/uvuk-lak-9mm.stl
14.0 x 14.0 x 9.00

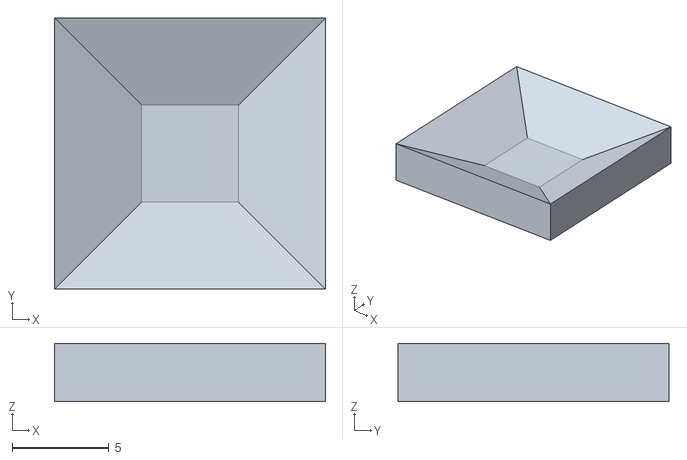
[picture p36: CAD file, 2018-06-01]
uvuk-stl/uvuk-lak-3mm.stl
14.0 x 14.0 x 3.00

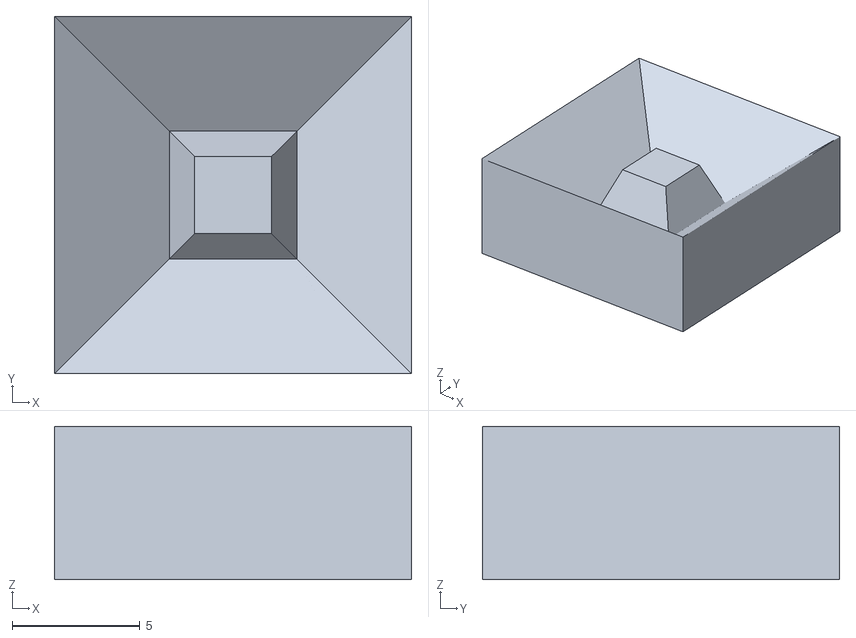
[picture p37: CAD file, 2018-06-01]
uvuk-stl/uvuk-pik-6mm.stl
14.0 x 14.0 x 6.00

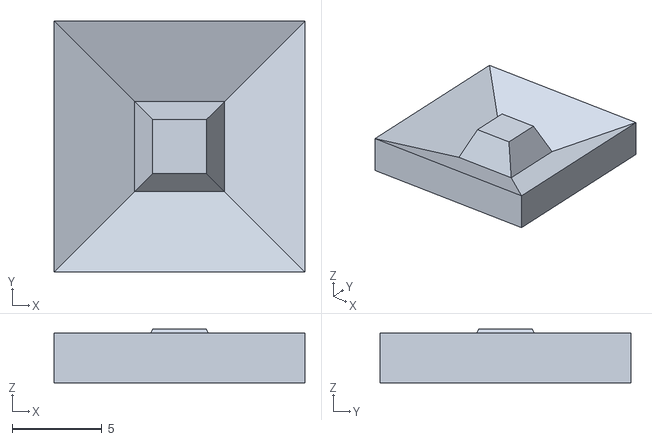
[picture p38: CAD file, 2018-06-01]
uvuk-stl/uvuk-pik-3mm.stl
14.0 x 14.0 x 3.00

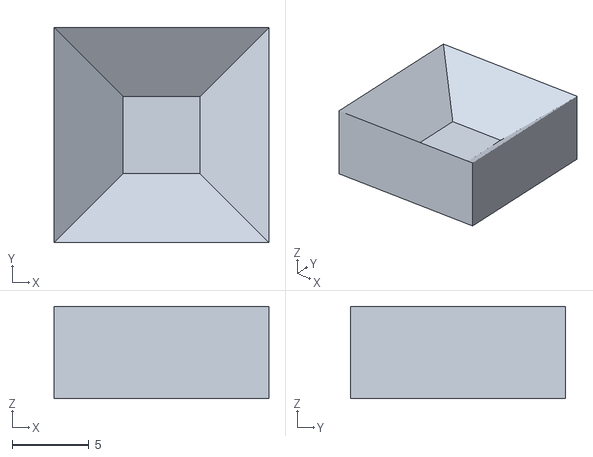
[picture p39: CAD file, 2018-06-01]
uvuk-stl/uvuk-lak-6mm.stl
14.0 x 14.0 x 6.00

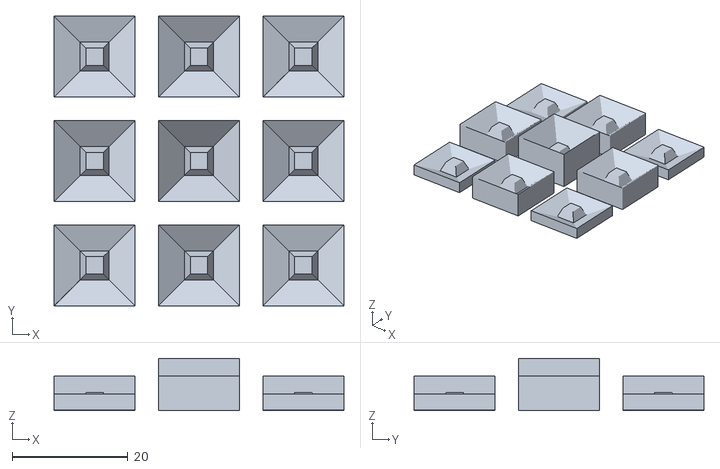
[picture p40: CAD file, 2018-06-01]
uvuk-stl/uvuk-ccv-face.stl
50.0 x 50.0 x 9.00

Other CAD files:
uvuk-stl/uvuk-pik-9mm.stl
uvuk-kte.blend

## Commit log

2018-06-01 UvuK Cube Blender 3D model
    [uvuk-kte.blend]
2018-07-22 UvuKiri
    UvuKiri plate 2mm
    [uvukiri-plate2mm.stl]
2018-07-22 UvuKiri
    UvuKiri cube support
    [uvukiri-cube.stl]
